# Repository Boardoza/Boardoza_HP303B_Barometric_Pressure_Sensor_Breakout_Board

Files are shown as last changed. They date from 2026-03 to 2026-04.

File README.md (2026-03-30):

# Boardoza HP303B Barometric Pressure and Temperature Sensor Breakout Board

The **Boardoza HP303B Breakout Board** is a compact and low-power digital **barometric pressure and temperature sensor** designed for applications requiring high accuracy and long-term stability. Based on a **capacitive pressure sensing principle**, the HP303B delivers precise measurements even under changing temperature conditions, making it suitable for demanding environmental sensing tasks.

Each HP303B sensor is **individually calibrated at the factory** and includes a **24-bit internal signal processor** that converts raw sensor data into accurate pressure and temperature values. With support for both **I²C and SPI communication**, an integrated **32-sample FIFO**, and optional **interrupt functionality**, this breakout board is ideal for **IoT devices, wearables, mobile electronics, weather stations, altitude measurement systems, and battery-powered sensor nodes**.

## [Click here to purchase!](https://www.ozdisan.com/p/arduino-sensorleri-ve-modulleri-613/boardoza-hp303b-module-1473941)

| Front Side | Back Side |
|:---:|:---:|
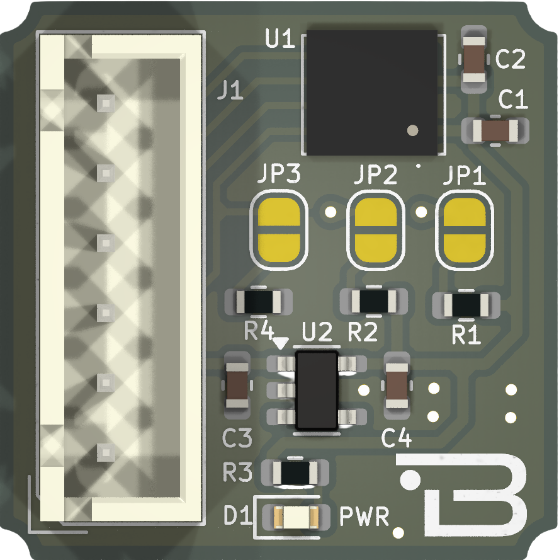
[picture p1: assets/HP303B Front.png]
HP303B Front
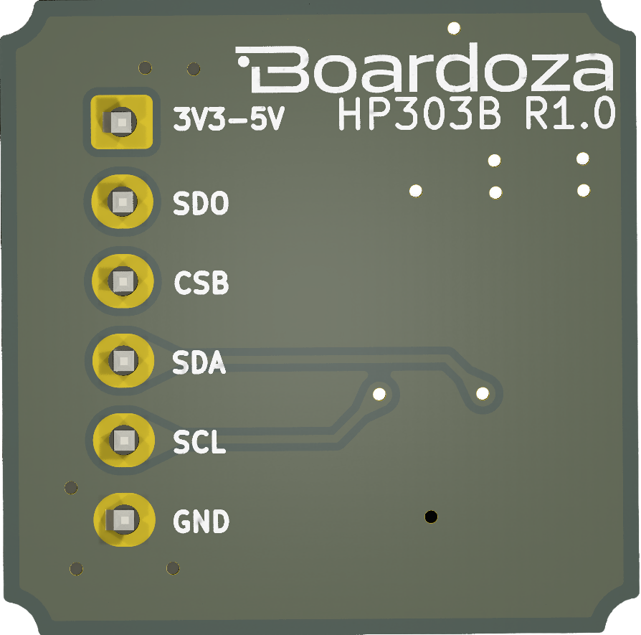
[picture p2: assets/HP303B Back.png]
HP303B Back
|  |  |

---

## Key Features

- **High-Accuracy Barometric Pressure Sensor:** Designed for precise pressure and altitude measurements across a wide operating range.
- **Integrated Temperature Measurement:** Provides accurate ambient temperature data alongside pressure readings.
- **Factory-Calibrated Sensor:** Each HP303B device is individually calibrated, ensuring reliable and consistent output.
- **Dual Communication Interface:** Supports both **I²C** and **SPI** interfaces for flexible system integration.
- **32-Sample FIFO Buffer:** Reduces host processor load by minimizing frequent data polling.
- **Low Power Consumption:** Optimized for battery-powered and low-energy applications such as wearables and IoT nodes.
- **Interrupt Support:** Optional interrupt signaling via the SDO pin for efficient event-driven designs.

---

## Technical Specifications

**Model:** HP303B  
**Manufacturer:** Boardoza   
**Manufacturer IC:** HOPERF  
**Functions:** Digital Barometric Pressure and Temperature Sensor  
**Supply Voltage:** 3.3 V – 5 V  
**Interface:** I²C, SPI  
**Pressure Measurement Range:** 300 hPa – 1200 hPa  
**Pressure Precision:** ±0.005 hPa (high precision mode)  
**Relative Accuracy:** ±0.06 hPa  
**Absolute Accuracy:** ±1 hPa  
**Temperature Accuracy:** ±0.5 °C  
**Pressure Temperature Sensitivity:** 0.5 Pa/K  
**Measurement Time:**  
- Typical: 27.6 ms (standard mode, 16x)  
- Minimum: 3.6 ms (low precision mode)  
  
**Average Current Consumption:**  
- Pressure Measurement: 1.7 µA @ 1 Hz  
- Temperature Measurement: 1.5 µA @ 1 Hz  
- Standby Mode: 0.5 µA

**FIFO Buffer Depth:** 32 samples  
**Operating Temperature:** -40 °C to +85 °C  
**Board Dimensions:** 20 mm x 20 mm

---

## Board Pinout

### **( J1 ) Main Connector**

| Pin Number | Pin Name | Description |
|:---:|:---:|---|
| 1 | 3V3-5V | Positive Power Supply |
| 2 | SDO | I²C: Address LSB / Interrupt<br>SPI: MISO / Interrupt |
| 3 | CSB | I²C: Not used (leave open)<br>SPI: Chip Select |
| 4 | SDA | I²C: Serial Data<br>SPI: MOSI (4-wire) / Data (3-wire) |
| 5 | SCL | I²C: Serial Clock<br>SPI: Serial Clock |
| 6 | GND | Ground |

### **Jumper Configuration**

| Jumper | Description |
|---|---|
| JP1, JP2 | SPI mode: Open (default)<br>I²C mode: Short |
| JP3 | I²C Address 0x77: Open (default)<br>I²C Address 0x76: Short |

---

## Board Dimensions

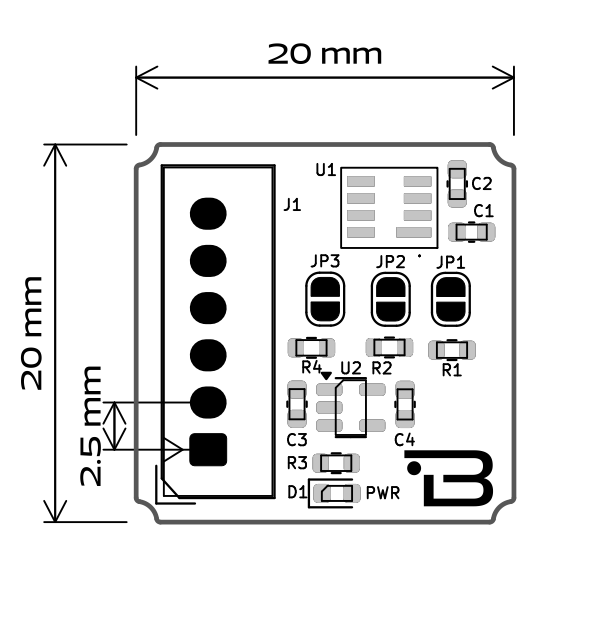
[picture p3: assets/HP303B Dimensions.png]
HP303B Board Dimensions


---

## Step Files

[Boardoza HP303B.step](./assets/HP303B%20Step.step)

---

## Datasheet

[HP303B Datasheet](./assets/HP303B%20Datasheet.pdf)

---

## Version History

- V1.0.0 – Initial Release

---

## Support

- If you have any questions or need support, please contact **support@boardoza.com**

---

## **License**

This repository contains both hardware and software components:

### **Hardware Design**

[][cc-by-sa]

All hardware design files are licensed under [Creative Commons Attribution-ShareAlike 4.0 International License][cc-by-sa].

[cc-by-sa]: http://creativecommons.org/licenses/by-sa/4.0/
[cc-by-sa-shield]: https://img.shields.io/badge/License-CC%20BY--SA%204.0-lightgrey.svg

### **Software/Firmware**

[][bsd]

All software and firmware are licensed under [BSD 3-Clause License][bsd].

[bsd]: https://opensource.org/licenses/BSD-3-Clause
[bsd-shield]: https://img.shields.io/badge/License-BSD%203--Clause-blue.svg

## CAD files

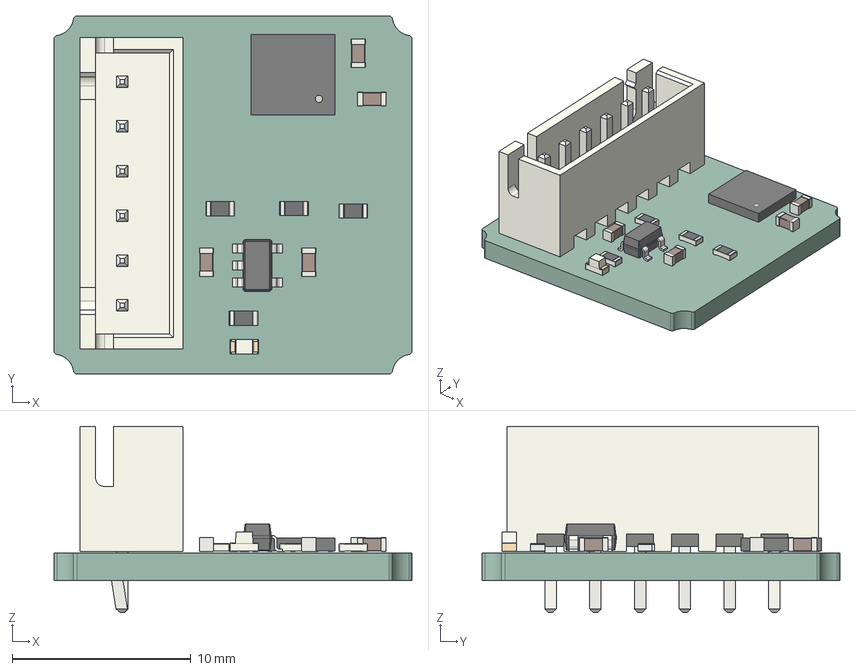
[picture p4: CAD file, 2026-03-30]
assets/HP303B Step.step
20.0 x 20.0 x 10.4 mm
AMS_LGA-20_4.7x4.5mm_P0.65mm
C_0603_1608Metric x 4
R_0603_1608Metric x 4
SOT-23-5
JST_XH_B6B-XH-A_1x06_P2.50mm_Vertical
LED_0603_1608Metric
B-HP303B-BRK_PCB

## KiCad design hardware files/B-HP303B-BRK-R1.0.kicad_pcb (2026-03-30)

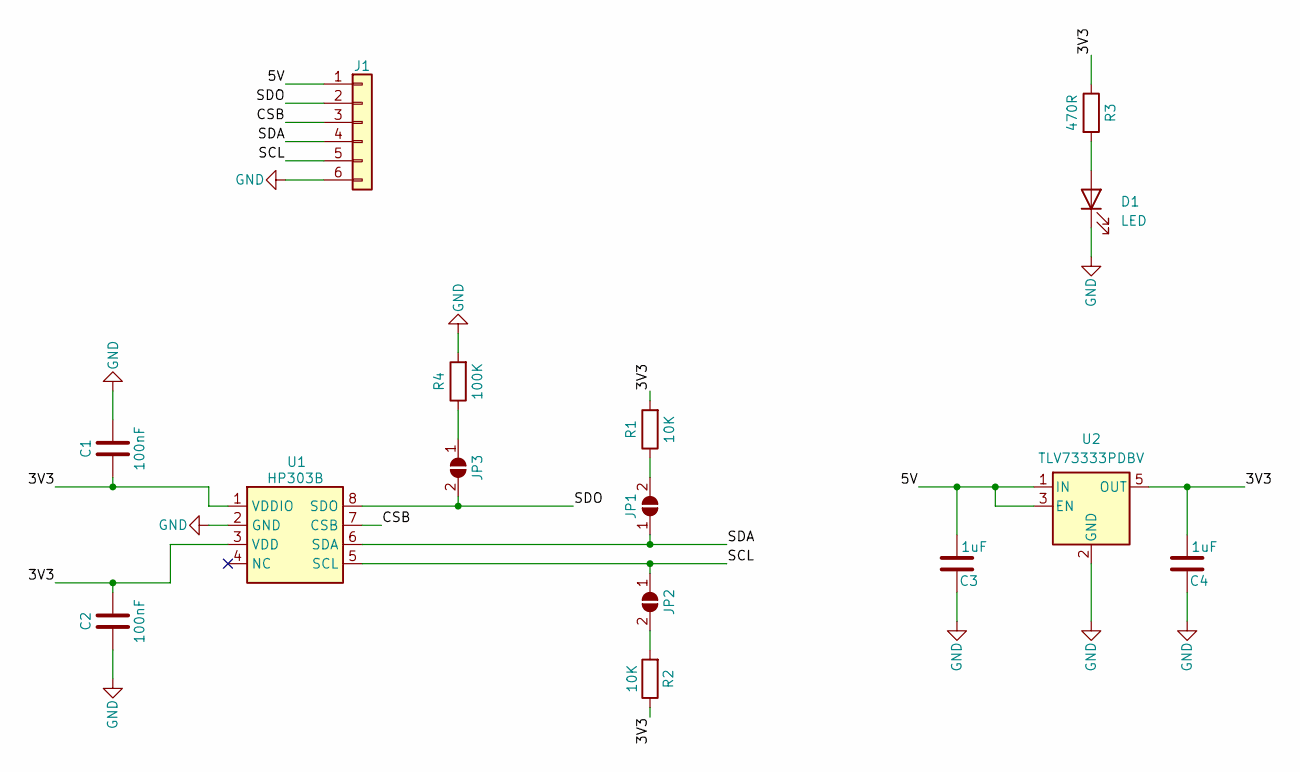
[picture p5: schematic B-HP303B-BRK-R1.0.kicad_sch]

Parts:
C1, C2: 100nF; C_0603_1608Metric
C3, C4: 1uF; C_0603_1608Metric
D1: LED; LED_0603_1608Metric
J1: Conn_01x06; 2317-06S_1x06_P2.50mm_Vertical
JP1: SDA; SolderJumper-2_P1.3mm_Open_RoundedPad1.0x1.5mm
JP2: SCK; SolderJumper-2_P1.3mm_Open_RoundedPad1.0x1.5mm
JP3: INT; SolderJumper-2_P1.3mm_Open_RoundedPad1.0x1.5mm
R1, R2: 10K; R_0603_1608Metric
R3: 470R; R_0603_1608Metric
R4: 100K; R_0603_1608Metric
U1: HP303B; MPN HP303B
U2: TLV73333PDBV; SOT-23-5; MPN TLV73333PDBV

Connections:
/3V3: C1.1, C2.2, C4.2, R1.2, R2.1, R3.1, U1.1 (VDDIO), U1.3 (VDD), U2.5 (OUT)
/5V: C3.2, J1.1, U2.1 (IN), U2.3 (EN)
/CSB: J1.3, U1.7 (CSB)
/SCL: J1.5, JP2.1 (A), U1.5 (SCL)
/SDA: J1.4, JP1.1 (A), U1.6 (SDA)
/SDO: J1.2, JP3.2 (B), U1.8 (SDO)
GND: C1.2, C2.1, C3.1, C4.1, D1.1 (K), J1.6, R4.2, U1.2 (GND), U2.2 (GND)
unnamed: D1.2 (A), R3.2
unnamed: JP1.2 (B), R1.1
unnamed: JP2.2 (B), R2.2
unnamed: JP3.1 (A), R4.1

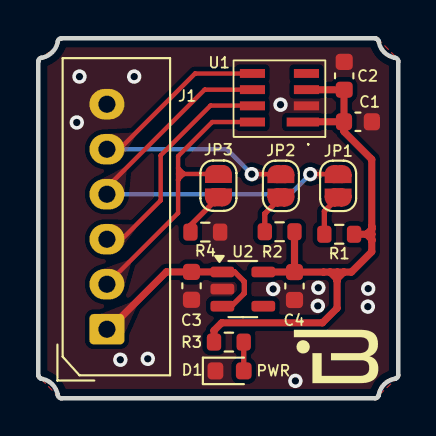
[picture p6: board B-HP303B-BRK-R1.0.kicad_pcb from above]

Board: 2 copper layers, 20.0 x 20.0 mm, 15 parts (0 on the bottom side), 11 nets.

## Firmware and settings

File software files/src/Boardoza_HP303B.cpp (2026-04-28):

#include "Boardoza_HP303B.h"

uint8_t rawData[16];
int32_t osrTable[8]={524288, 1572864, 3670016, 7864320, 253952, 516096, 1040384, 2088960};
int16_t prs_osr = 0x03;
int16_t temp_osr = 0x03;
double scaledTemp;

// SPI Settings: 1MHz speed, MSB First, MODE3
SPISettings hp303b_spi_settings(1000000, MSBFIRST, SPI_MODE3);

Boardoza_HP303B::Boardoza_HP303B(void) {
    _useSPI = false; // Default
}

void Boardoza_HP303B::begin(TwoWire &wire, uint8_t slaveAddress) {
    _useSPI = false;
    _wire = &wire;
    _i2cAddress = slaveAddress;
    _wire->begin();
}

void Boardoza_HP303B::begin(uint8_t slaveAddress) {
    begin(Wire, slaveAddress);
}

void Boardoza_HP303B::begin(SPIClass &spi, int32_t chipSelect) {
    _useSPI = true;
    _spi = &spi;
    _chipSelect = chipSelect;
    pinMode(_chipSelect, OUTPUT);
    digitalWrite(_chipSelect, HIGH);
    _spi->begin();
    // SPI test transaction (not necessary, but can remain to wake up the bus)
    _spi->beginTransaction(hp303b_spi_settings);
    _spi->endTransaction();
}

void Boardoza_HP303B::end(void) {
    if (!_useSPI) {
        // Wire end function does not exist on some platforms, use it if available.
    } else {
        _spi->end();
        pinMode(_chipSelect, INPUT);
    }
}

void Boardoza_HP303B::configIntFIFO() {
    if(temp_osr <= 0x03) writeByte(CFG_REG, 0x00);
    else writeByte(CFG_REG, 0x0C);
    
    if(prs_osr > 0x03) writeByte(CFG_REG, 0x0C); 
}

int16_t Boardoza_HP303B::correctTemp(void) {
    writeByte(0x0E, 0xA5);
    writeByte(0x0F, 0x96);
    writeByte(0x62, 0x02);
    writeByte(0x0E, 0x00);
    writeByte(0x0F, 0x00);
    return 0;
}

void Boardoza_HP303B::configPressure(uint8_t prs_mr, uint8_t prs_osr) {
    writeByte(PRS_CFG, (prs_mr << 4 | prs_osr));
}

void Boardoza_HP303B::configTemp(bool temp_ext, uint8_t temp_mr, uint8_t temp_osr) {
    writeByte(TMP_CFG, (temp_ext << 7 | temp_mr << 4 | temp_osr));
}

void Boardoza_HP303B::setOpMode(Mode opMode) {
    writeByte(MEAS_CFG, opMode);
}

int16_t Boardoza_HP303B::readReg() {
    return readByte(PRODUCT_ID);
}

int32_t Boardoza_HP303B::measureRawTemp() {
    int32_t tempData;
    if (!readBlock(0x03, 3, rawData)) {
        tempData = (uint32_t)rawData[0] << 16;
        tempData |= (uint32_t)rawData[1] << 8;
        tempData |= (uint32_t)rawData[2];
        return tempData;
    } 
    return -1;
}

int32_t Boardoza_HP303B::measureTemperature() {
    int32_t tempData1, tempData2; 
    int32_t C0, C1;
    int32_t temp3;
    double temp4;
    tempData1 = (uint32_t)(readByte(COEF_C0) << 4);
    tempData2 = (uint32_t)((readByte(COEF_C0C1) >> 4) & 0x0F);

    C0 = (uint32_t)tempData1 | (uint32_t)tempData2;
    if(C0 & ((uint32_t)1 << 11)) C0 -= (uint32_t)1 << 12;
    C0 = C0 / 2;

    tempData1 = (uint32_t)((readByte(COEF_C0C1)& 0x0F) << 8);
    tempData2 = (uint32_t)(readByte(COEF_C1));
    C1 = (uint32_t)tempData1 | (uint32_t)tempData2;
    if(C1 & ((uint32_t)1 << 11)) C1 -= (uint32_t)1 << 12;
    
    temp3 = measureRawTemp();
    if(temp3 & ((uint32_t)1 << 23)) temp3 -= (uint32_t)1 << 24;
    
    scaledTemp = (double)temp3;
    scaledTemp = scaledTemp / osrTable[temp_osr];
    temp4 = (double)temp3;
    temp4 = temp4 / osrTable[temp_osr];
    temp4 = ((double)C0) + (double)C1 * (double)temp4;

    return (int32_t)(temp4);
}

int32_t Boardoza_HP303B::measureRawPres() {
    int32_t tempData;
    if (!readBlock(PSR_B2, 3, rawData)) {
        tempData = (uint32_t)rawData[0] << 16;
        tempData |= (uint32_t)(rawData[1] << 8);
        tempData |= (uint32_t)(rawData[2]);
        return tempData;
    } 
    return -1;
}
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

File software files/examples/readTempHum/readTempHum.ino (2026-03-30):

#include <SPI.h>
#include "Boardoza_HP303B.h"

#define HP303B_CS_PIN 5

Boardoza_HP303B sensor;

void setup() {
  Serial.begin(115200);
  while (!Serial);

  Serial.println("Initializing Boardoza HP303B...");
  
  sensor.begin(SPI, HP303B_CS_PIN);
  sensor.correctTemp();
  
  delay(100);
  Serial.println("Sensor Ready!");
}

void loop() {
  sensor.setOpMode(CMD_TEMP);
  delay(50);
  int32_t temperature = sensor.measureTemperature();

  sensor.setOpMode(CMD_PRES);
  delay(50);
  int32_t pressure = sensor.measurePressure();

  Serial.print("Temp: ");
  Serial.print(temperature);
  Serial.print(" C\t");

  Serial.print("Press: ");
  Serial.print(pressure);
  Serial.println(" Pa");

  delay(1000);
}

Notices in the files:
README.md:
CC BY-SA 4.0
